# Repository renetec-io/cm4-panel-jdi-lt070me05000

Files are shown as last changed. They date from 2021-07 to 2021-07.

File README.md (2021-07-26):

Overview
======

This repository contains a PCB design and drivers for Raspberry Pi CM4 Сarrier with Hi-Res MIPI Display project.<br>
For details, see https://hackaday.io/project/176098-raspberry-pi-cm4-arrier-with-hi-res-mipi-display

The display used is JDI LT070ME05000 with Goodix touch input driver IC. The project also uses MCP23008 IO expander to save some GPIO pins.

Raspberry Pi only supports its official 7-inch MIPI DSI display with FKMS(Fake/Firmware KMS) out of the box. 
To make the display work, we need to use full KMS and Linux kernel driver for the panel.

The PCB design is contained in the KiCAD directory.

Setup
======

1. Install the latest Raspberry PI OS image, either on SD card (with CM4 Lite) or onto eMMC.
   With Lite version, you can use [SD card instruction](https://www.raspberrypi.org/documentation/installation/installing-images), 
   otherwise use [eMMC instruction](https://www.raspberrypi.org/documentation/hardware/computemodule/cm-emmc-flashing.md).   
   The jumper that enables boot from usb is located near the micro-USB connector on the PCB.
   
1. Mount `boot` partition onto your computer.

1. Enable and connect the serial console.
   1. Add `enable_uart=1` to the config.txt file on `boot` partition.   
   1. Use the serial interface to connect to Raspberry Pi: [elinux.org instruction](https://elinux.org/RPi_Serial_Connection).   
   
1. Enable USB port. <br>
   By default, to conserve power, USB is not enabled on CM4.<br>
   To enable, add `dtoverlay=dwc2,dr_mode=host` to config.txt.
   
1. Boot your Raspberry Pi and connect it to the internet. If you have a module without Wi-Fi, 
   you need a USB Wi-Fi or Ethernet adapter. 
   If Wi-Fi doesn't work, and you are receiving the message like "Could not communicate with wpa_supplicant" from raspi-config 
   when trying to set up wireless network, you may need to add the following
   ```
   allow-hotplug wlan0
   iface wlan0 inet manual
   wpa-conf /etc/wpa_supplicant/wpa_supplicant.conf
   ```
   to /etc/network/interfaces and then reboot.

1. On the Raspberry Pi, 
   1. Install git and dkms: 
   ```
   sudo apt-get update
   sudo apt-get install git dkms
   ```
   2. Clone the repository and install the drivers
   ```
   git clone https://github.com/renetec-io/cm4-panel-jdi-lt070me05000.git
   cd cm4-panel-jdi-lt070me05000
   ./setup.sh
   ```

1. Enable display driver.<br>
   Add the following in the end of /boot/config.txt:
   ```
   dtparam=i2c_vc=on   
   lcd_ignore=1   
   dtoverlay=vc4-kms-v3d-pi4,noaudio   
   dtoverlay=cm4-dsi-lt070me05000   
   ```
   
1. Enable sound.<br>
   Add the following to /boot/config.txt:
   ```
   # Sound configuration   
   dtparam=audio=on   
   dtoverlay=hifiberry-dac   
   dtoverlay=i2s-mmap   
   ```   

8. Reboot.

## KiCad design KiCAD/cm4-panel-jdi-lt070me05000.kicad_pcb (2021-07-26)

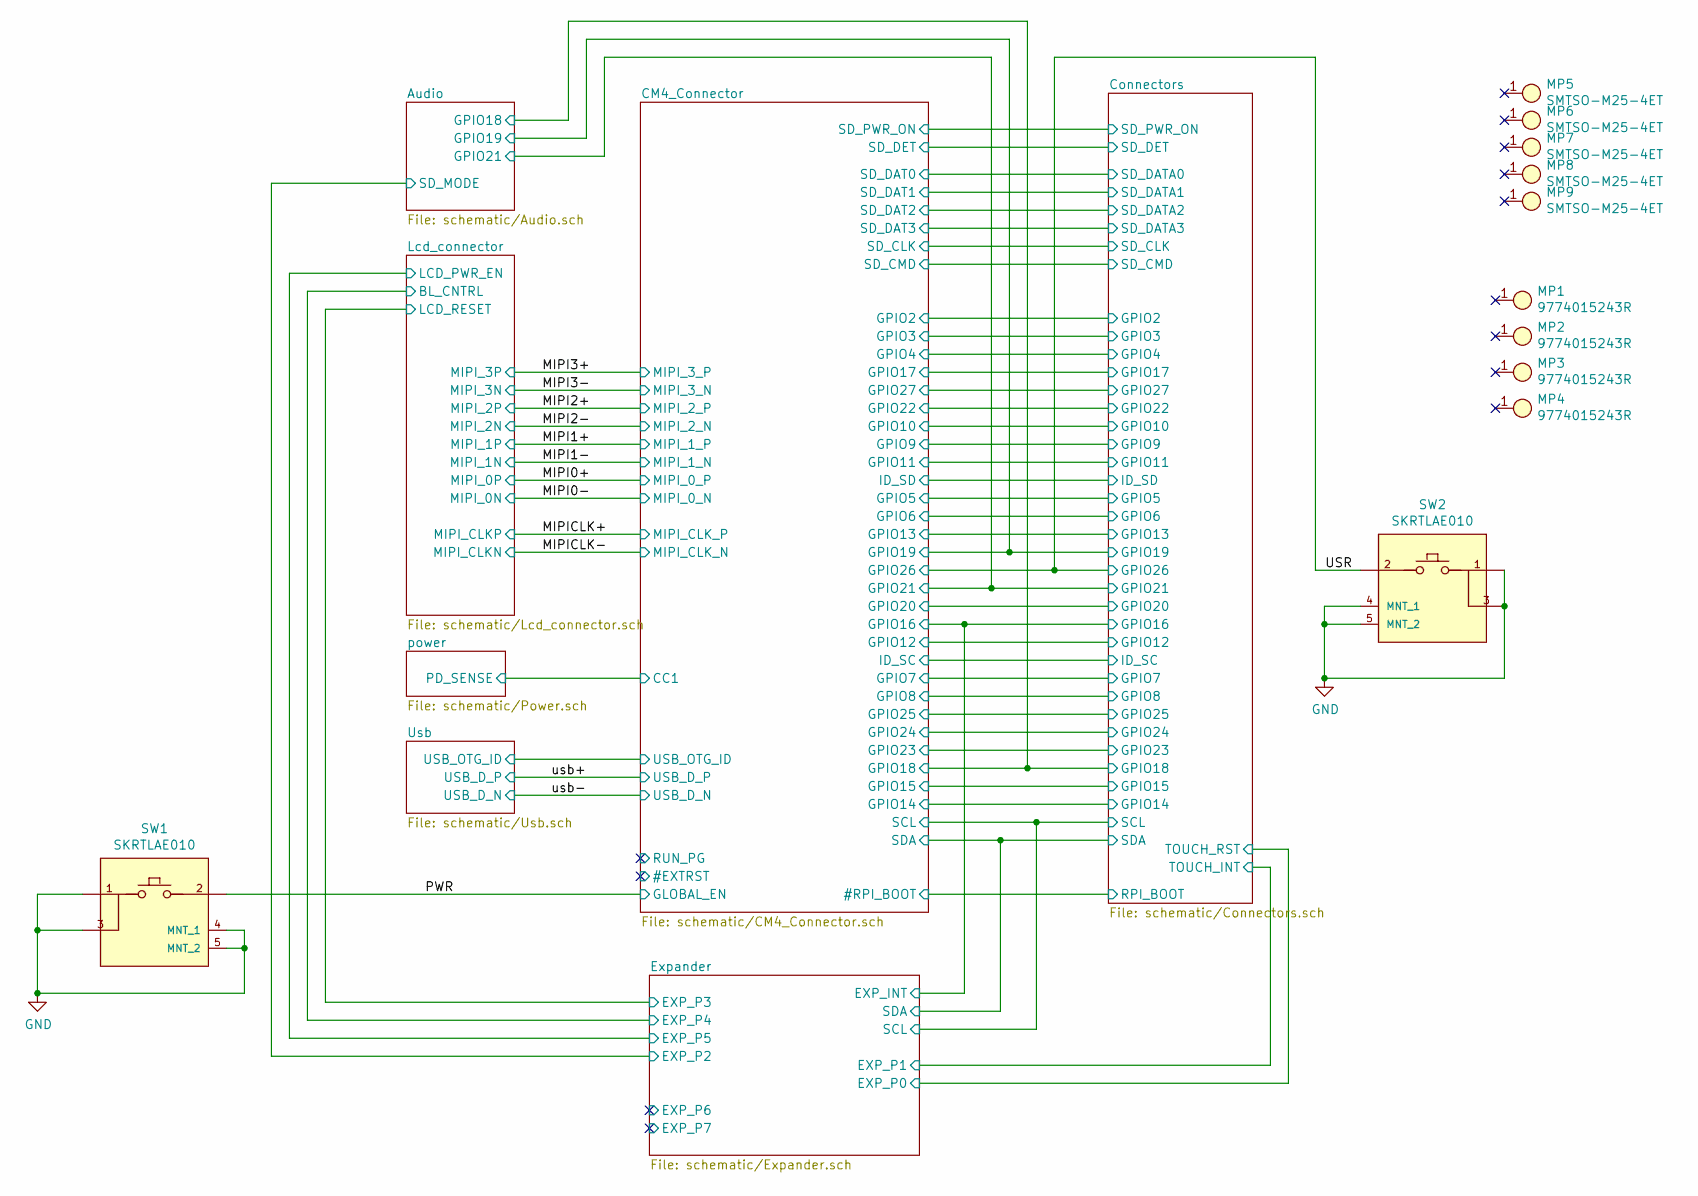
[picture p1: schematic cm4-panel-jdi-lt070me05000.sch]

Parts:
MP1, MP2, MP3, MP4: 9774015243R
MP5, MP6, MP7, MP8, MP9: SMTSO-M25-4ET
SW1, SW2: SKRTLAE010; ALPS-SKRTLAE010-0-0-0; voltage rating DC 12V; mouser part number 688-SKRTLA; mouser description Switch Tactile N.O. SPST Round Button J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

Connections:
/PWR: SW1.2; also elsewhere on the board
/USR: SW2.2; also elsewhere on the board
GND: SW1.1, SW1.3, SW1.4 (MNT_1), SW1.5 (MNT_2), SW2.1, SW2.3, SW2.4 (MNT_1), SW2.5 (MNT_2); also elsewhere on the board

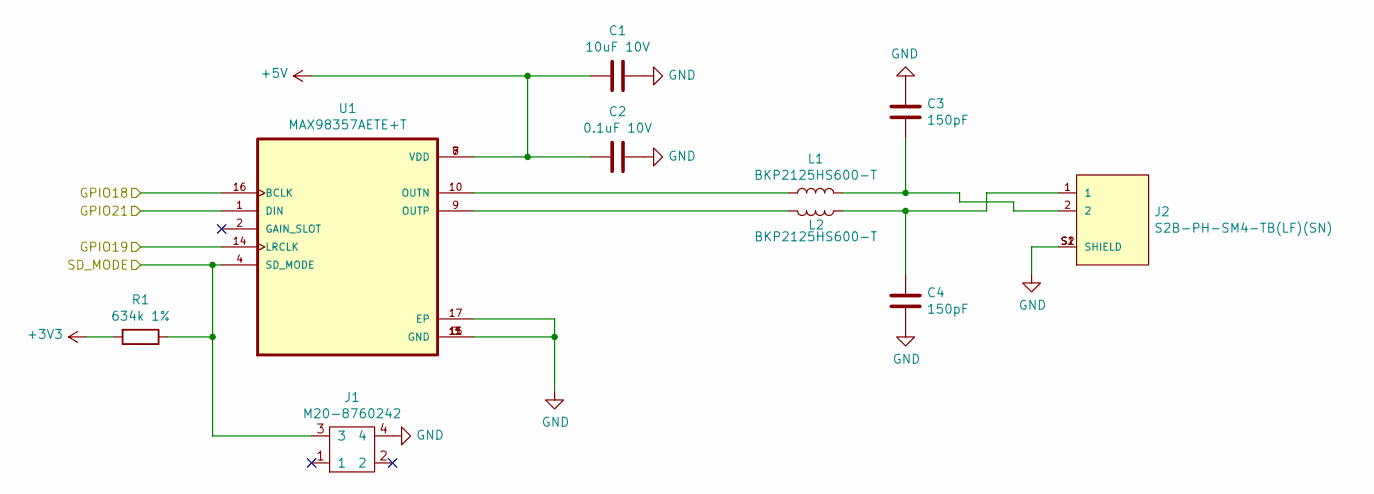
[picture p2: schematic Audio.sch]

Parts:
C1: 10uF 10V; C_0603_1608Metric
C2: 0.1uF 10V; C_0603_1608Metric
C3, C4: 150pF; C_0603_1608Metric
J1: M20-8760242
J2: S2B-PH-SM4-TB(LF)(SN); JST_S2B-PH-SM4-TB(LF)(SN)
L1, L2: BKP2125HS600-T; L_0805_2012Metric
R1: 634k 1%; R_0603_1608Metric
U1: MAX98357AETE+T; QFN50P300X300X80-17N

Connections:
+3V3: R1.2; also elsewhere on the board
+5V: C1.2, C2.2, U1.7 (VDD), U1.8 (VDD); also elsewhere on the board
/Audio/GPIO18: U1.16 (BCLK); also elsewhere on the board
/Audio/GPIO19: U1.14 (LRCLK); also elsewhere on the board
/Audio/GPIO21: U1.1 (DIN); also elsewhere on the board
/Expander/EXP_P2: J1.3, R1.1, U1.4 (SD_MODE); also elsewhere on the board
GND: C1.1, C2.1, C3.2, C4.1, J1.4, J2.S1 (SHIELD), J2.S2 (SHIELD), U1.3 (GND), U1.11 (GND), U1.15 (GND), U1.17 (EP); also elsewhere on the board
unnamed: C3.1, J2.2, L1.2
unnamed: C4.2, J2.1, L2.2
unnamed: L1.1, U1.10 (OUTN)
unnamed: L2.1, U1.9 (OUTP)

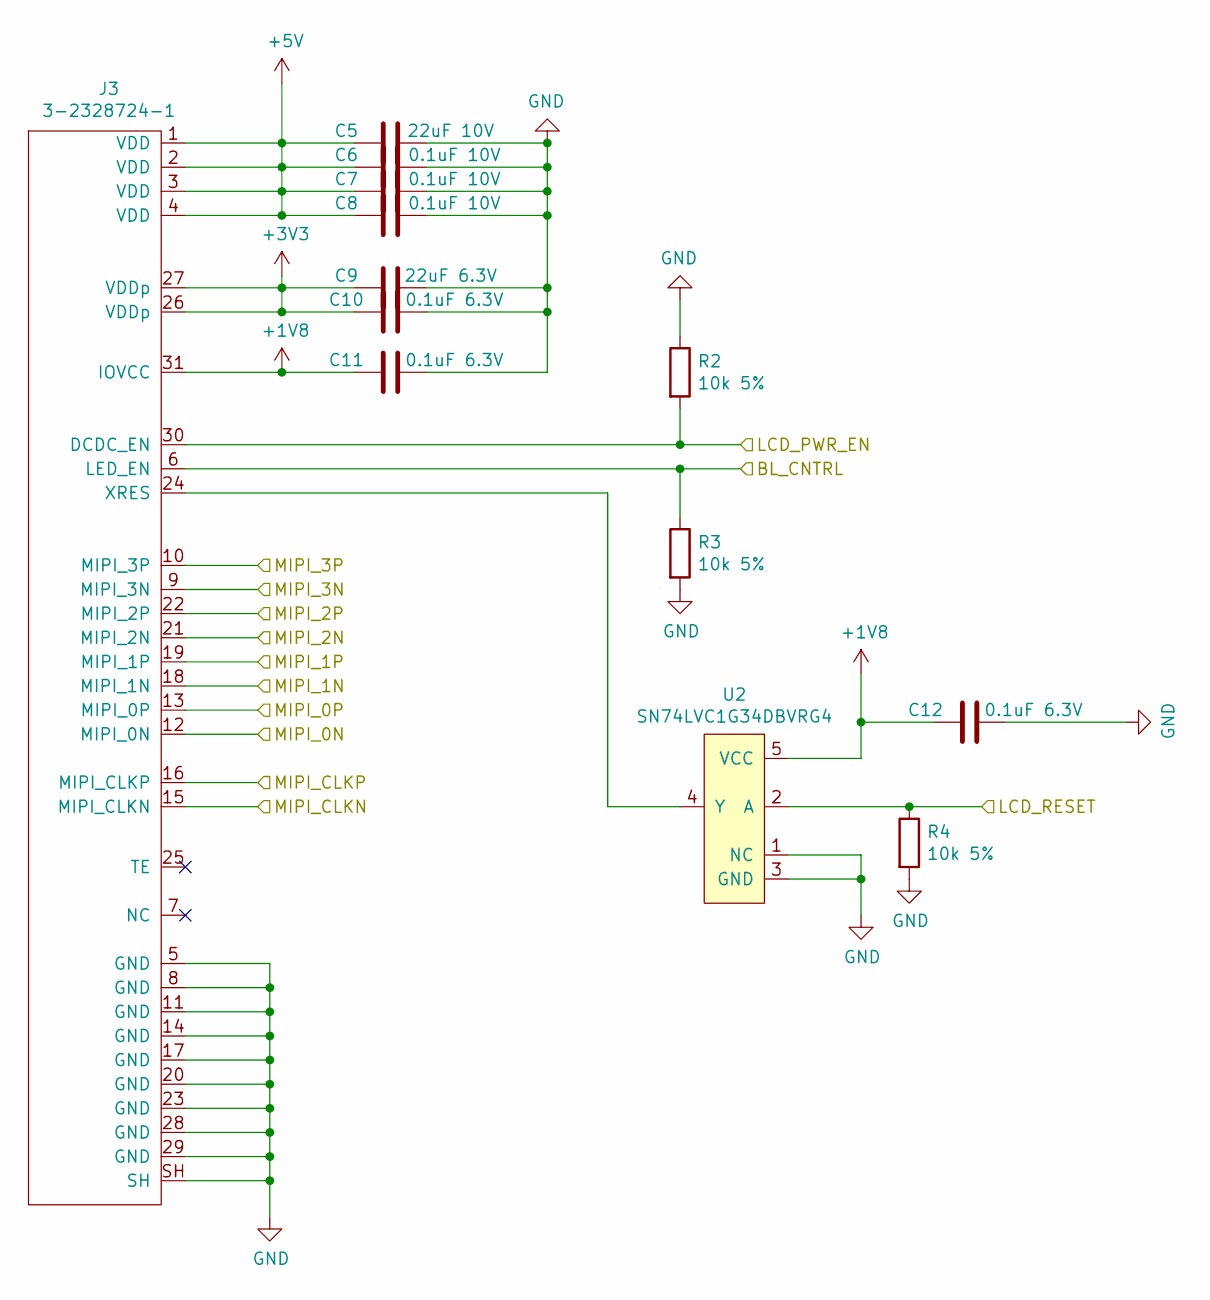
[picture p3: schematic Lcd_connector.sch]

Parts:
C5: 22uF 10V; C_0805_2012Metric
C6, C7, C8: 0.1uF 10V; C_0603_1608Metric
C9: 22uF 6.3V; C_0805_2012Metric
C10, C11, C12: 0.1uF 6.3V; C_0603_1608Metric
J3: 3-2328724-1
R2, R3, R4: 10k 5%; R_0603_1608Metric
U2: SN74LVC1G34DBVRG4; SOT95P280X145-5N

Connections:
+1V8: C11.2, C12.2, J3.31 (IOVCC), U2.5 (VCC); also elsewhere on the board
+3V3: C9.2, C10.2, J3.26 (VDDp), J3.27 (VDDp); also elsewhere on the board
+5V: C5.2, C6.2, C7.2, C8.2, J3.1 (VDD), J3.2 (VDD), J3.3 (VDD), J3.4 (VDD); also elsewhere on the board
/Expander/EXP_P3: R4.1, U2.2 (A); also elsewhere on the board
/Expander/EXP_P5: J3.30 (DCDC_EN), R2.2; also elsewhere on the board
/Lcd_connector/BL_CNTRL: J3.6 (LED_EN), R3.1; also elsewhere on the board
/MIPI0+: J3.13 (MIPI_0P); also elsewhere on the board
/MIPI0-: J3.12 (MIPI_0N); also elsewhere on the board
/MIPI1+: J3.19 (MIPI_1P); also elsewhere on the board
/MIPI1-: J3.18 (MIPI_1N); also elsewhere on the board
/MIPI2+: J3.22 (MIPI_2P); also elsewhere on the board
/MIPI2-: J3.21 (MIPI_2N); also elsewhere on the board
/MIPI3+: J3.10 (MIPI_3P); also elsewhere on the board
/MIPI3-: J3.9 (MIPI_3N); also elsewhere on the board
/MIPICLK+: J3.16 (MIPI_CLKP); also elsewhere on the board
/MIPICLK-: J3.15 (MIPI_CLKN); also elsewhere on the board
GND: C5.1, C6.1, C7.1, C8.1, C9.1, C10.1, C11.1, C12.1, J3.5 (GND), J3.8 (GND), J3.11 (GND), J3.14 (GND), J3.17 (GND), J3.20 (GND), J3.23 (GND), J3.28 (GND), J3.29 (GND), J3.SH, R2.1, R3.2, R4.2, U2.1 (NC), U2.3 (GND); also elsewhere on the board
unnamed: J3.24 (XRES), U2.4 (Y)

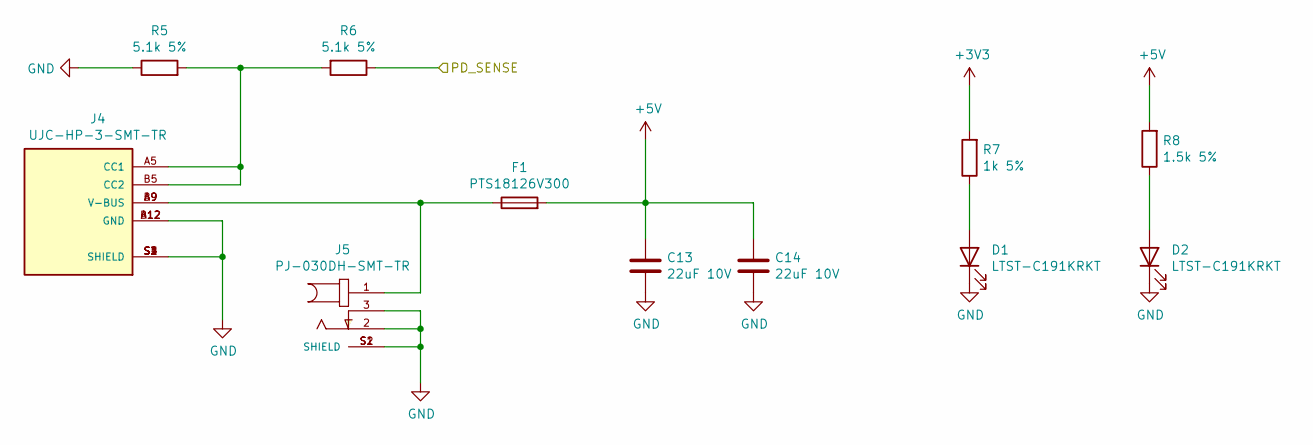
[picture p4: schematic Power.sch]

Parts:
C13, C14: 22uF 10V; C_0805_2012Metric
D1, D2: LTST-C191KRKT; LED_0603_1608Metric
F1: PTS18126V300; Fuse_1812_4532Metric
J4: UJC-HP-3-SMT-TR; CUI_UJC-HP-3-SMT-TR; PARTREV 1.0
J5: PJ-030DH-SMT-TR; CUI_PJ-030DH-SMT-TR; PARTREV 1.03
R5, R6: 5.1k 5%; R_0603_1608Metric
R7: 1k 5%; R_0603_1608Metric
R8: 1.5k 5%; R_0603_1608Metric

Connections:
+3V3: R7.2; also elsewhere on the board
+5V: C13.1, C14.1, F1.2, R8.2; also elsewhere on the board
/CM4_Connector/CC1: R6.1; also elsewhere on the board
GND: C13.2, C14.2, D1.1 (K), D2.1 (K), J4.A12 (GND), J4.B12 (GND), J4.S1 (SHIELD), J4.S2 (SHIELD), J4.S3 (SHIELD), J4.S4 (SHIELD), J5.2, J5.3, J5.S1 (SHIELD), J5.S2 (SHIELD), R5.1; also elsewhere on the board
unnamed: D1.2 (A), R7.1
unnamed: D2.2 (A), R8.1
unnamed: F1.1, J4.A9 (V-BUS), J4.B9 (V-BUS), J5.1
unnamed: J4.A5 (CC1), J4.B5 (CC2), R5.2, R6.2

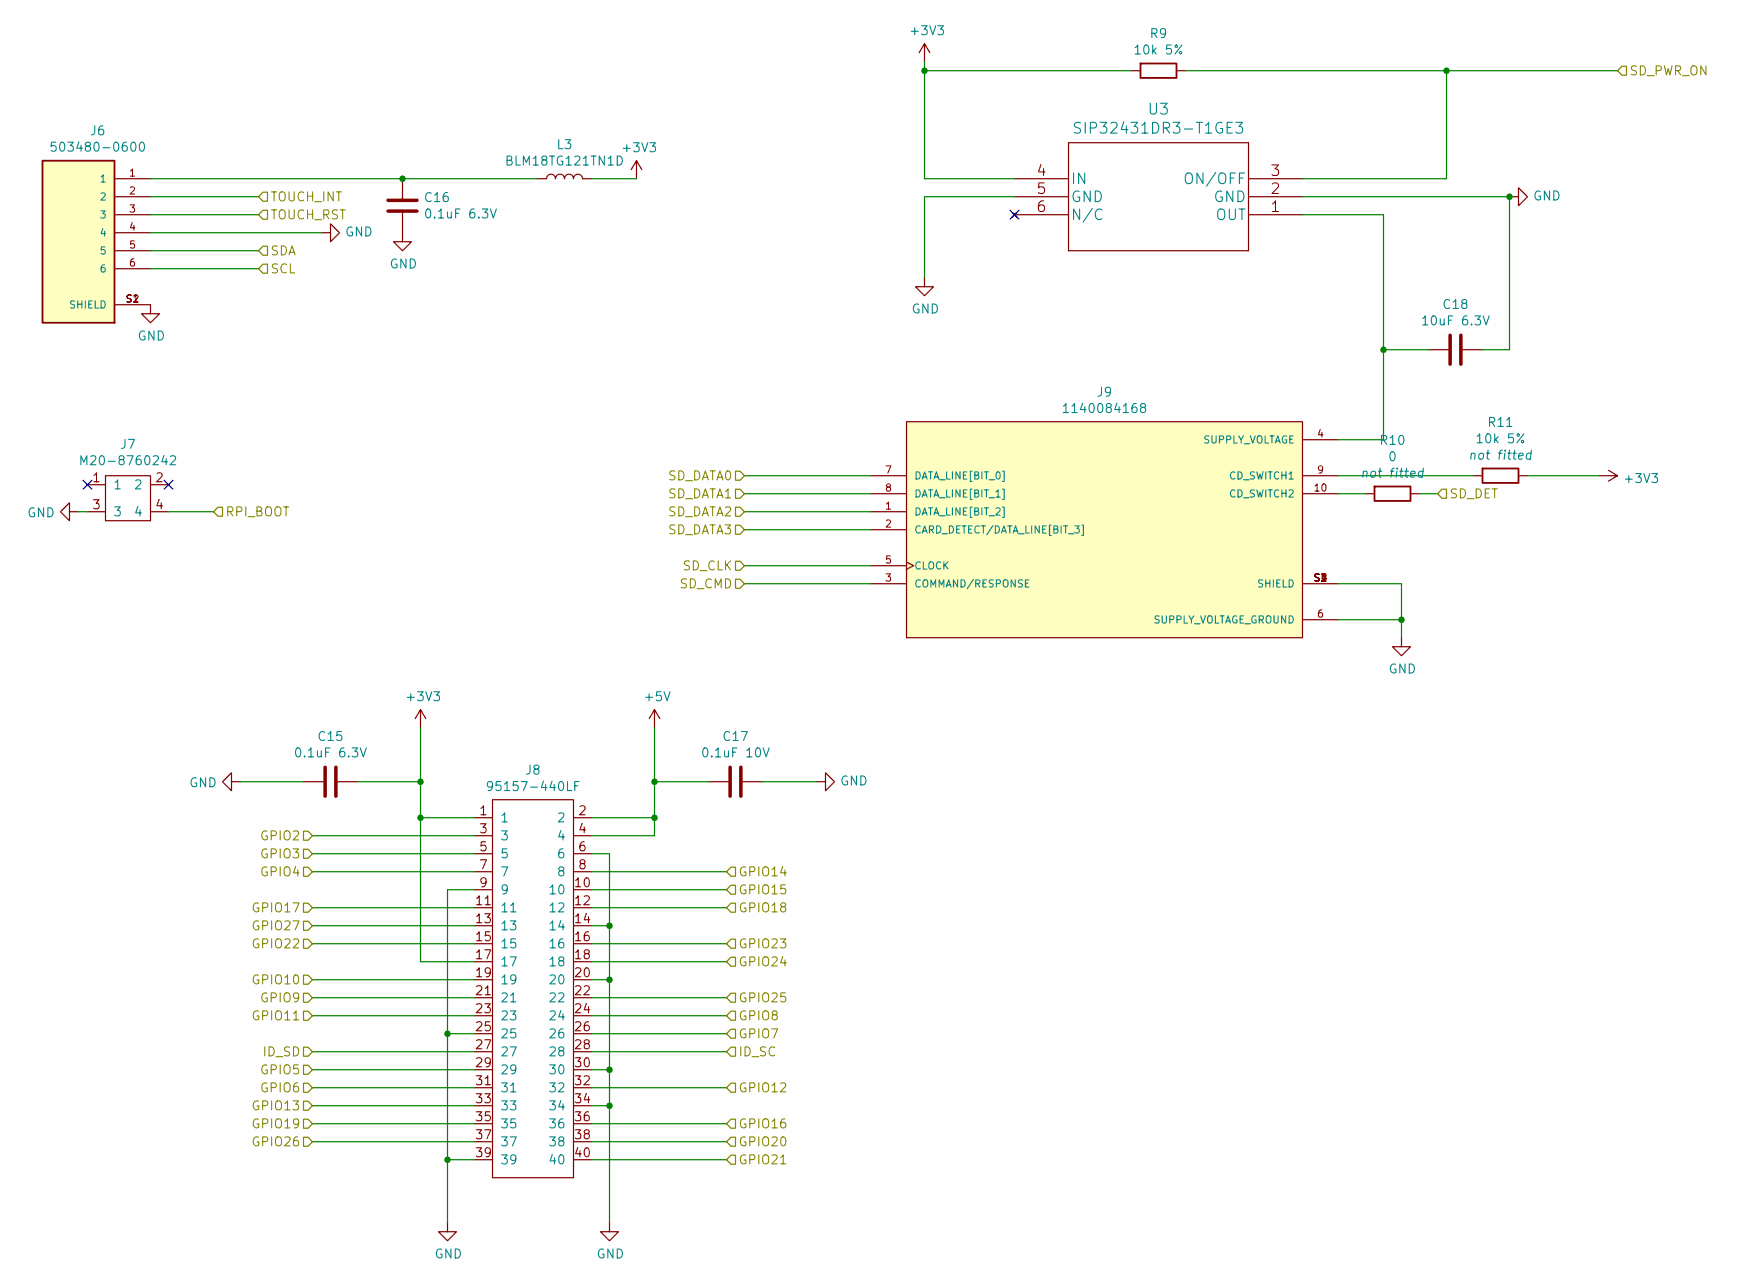
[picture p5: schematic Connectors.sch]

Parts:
C15, C16: 0.1uF 6.3V; C_0603_1608Metric
C17: 0.1uF 10V; C_0603_1608Metric
C18: 10uF 6.3V; C_0603_1608Metric
J6: 503480-0600; MOLEX_503480-0600; PARTREV H
J7: M20-8760242
J8: 95157-440LF
J9: 1140084168; AMPHENOL_1140084168; PARTREV A
L3: BLM18TG121TN1D; L_0603_1608Metric
R9, R11: 10k 5%; R_0603_1608Metric
R10: 0; R_0603_1608Metric
U3: SIP32431DR3-T1GE3

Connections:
+3V3: C15.1, J8.1, J8.17, L3.2, R9.2, R11.1, U3.4 (IN); also elsewhere on the board
+5V: C17.2, J8.2, J8.4; also elsewhere on the board
/Audio/GPIO18: J8.12; also elsewhere on the board
/Audio/GPIO19: J8.35; also elsewhere on the board
/Audio/GPIO21: J8.40; also elsewhere on the board
/CM4_Connector/#RPI_BOOT: J7.4; also elsewhere on the board
/CM4_Connector/GPIO2: J8.3; also elsewhere on the board
/CM4_Connector/GPIO3: J8.5; also elsewhere on the board
/CM4_Connector/GPIO4: J8.7; also elsewhere on the board
/CM4_Connector/GPIO5: J8.29; also elsewhere on the board
/CM4_Connector/GPIO6: J8.31; also elsewhere on the board
/CM4_Connector/GPIO7: J8.26; also elsewhere on the board
/CM4_Connector/GPIO8: J8.24; also elsewhere on the board
/CM4_Connector/GPIO9: J8.21; also elsewhere on the board
/CM4_Connector/GPIO10: J8.19; also elsewhere on the board
/CM4_Connector/GPIO11: J8.23; also elsewhere on the board
/CM4_Connector/GPIO12: J8.32; also elsewhere on the board
/CM4_Connector/GPIO13: J8.33; also elsewhere on the board
/CM4_Connector/GPIO14: J8.8; also elsewhere on the board
/CM4_Connector/GPIO15: J8.10; also elsewhere on the board
/CM4_Connector/GPIO17: J8.11; also elsewhere on the board
/CM4_Connector/GPIO20: J8.38; also elsewhere on the board
/CM4_Connector/GPIO22: J8.15; also elsewhere on the board
/CM4_Connector/GPIO23: J8.16; also elsewhere on the board
/CM4_Connector/GPIO24: J8.18; also elsewhere on the board
/CM4_Connector/GPIO25: J8.22; also elsewhere on the board
/CM4_Connector/GPIO27: J8.13; also elsewhere on the board
/CM4_Connector/ID_SC: J8.28; also elsewhere on the board
/CM4_Connector/ID_SD: J8.27; also elsewhere on the board
/CM4_Connector/SCL: J6.6; also elsewhere on the board
/CM4_Connector/SDA: J6.5; also elsewhere on the board
/CM4_Connector/SD_CLK: J9.5 (CLOCK); also elsewhere on the board
/CM4_Connector/SD_CMD: J9.3 (COMMAND/RESPONSE); also elsewhere on the board
/CM4_Connector/SD_DAT0: J9.7 (DATA_LINE[BIT_0]); also elsewhere on the board
/CM4_Connector/SD_DAT1: J9.8 (DATA_LINE[BIT_1]); also elsewhere on the board
/CM4_Connector/SD_DAT2: J9.1 (DATA_LINE[BIT_2]); also elsewhere on the board
/CM4_Connector/SD_DAT3: J9.2 (CARD_DETECT/DATA_LINE[BIT_3]); also elsewhere on the board
/CM4_Connector/SD_DET: R10.1; also elsewhere on the board
/CM4_Connector/SD_PWR_ON: R9.1, U3.3 (ON/OFF); also elsewhere on the board
/Expander/EXP_INT: J8.36; also elsewhere on the board
/Expander/EXP_P0: J6.3; also elsewhere on the board
/Expander/EXP_P1: J6.2; also elsewhere on the board
/USR: J8.37; also elsewhere on the board
GND: C15.2, C16.1, C17.1, C18.1, J6.4, J6.S1 (SHIELD), J6.S2 (SHIELD), J7.3, J8.6, J8.9, J8.14, J8.20, J8.25, J8.30, J8.34, J8.39, J9.6 (SUPPLY_VOLTAGE_GROUND), J9.S1 (SHIELD), J9.S2 (SHIELD), J9.S3 (SHIELD), J9.S4 (SHIELD), U3.2 (GND), U3.5 (GND); also elsewhere on the board
unnamed: C16.2, J6.1, L3.1
unnamed: C18.2, J9.4 (SUPPLY_VOLTAGE), U3.1 (OUT)
unnamed: J9.9 (CD_SWITCH1), R11.2
unnamed: J9.10 (CD_SWITCH2), R10.2

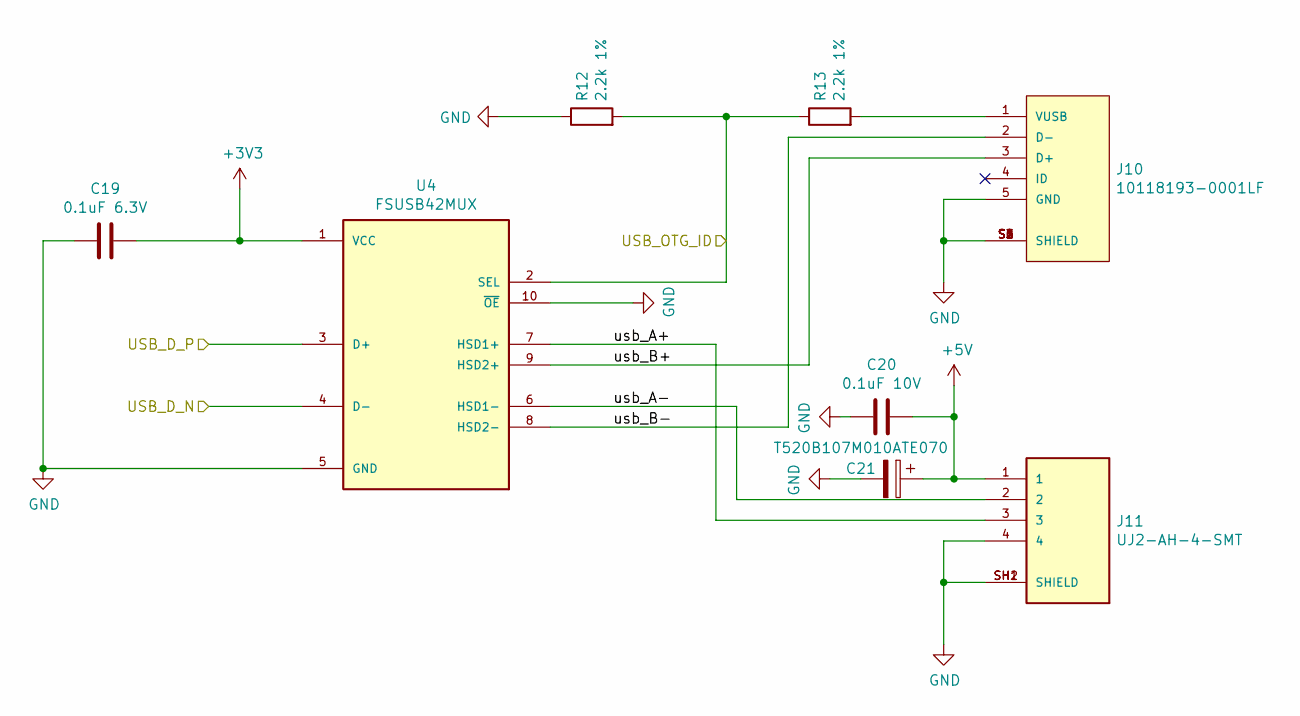
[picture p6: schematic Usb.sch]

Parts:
C19: 0.1uF 6.3V; C_0603_1608Metric
C20: 0.1uF 10V; C_0603_1608Metric
C21: T520B107M010ATE070; T520B227M006ATE045
J10: 10118193-0001LF; FCI_10118193-0001LF
J11: UJ2-AH-4-SMT; CUI_UJ2-AH-4-SMT; PART_REV 1.01
R12, R13: 2.2k 1%; R_0603_1608Metric
U4: FSUSB42MUX; SOP50P490X110-10N; PARTREV 1.25

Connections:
+3V3: C19.1, U4.1 (VCC); also elsewhere on the board
+5V: C20.1, C21.1, J11.1; also elsewhere on the board
/CM4_Connector/USB_OTG_ID: R12.2, R13.1, U4.2 (SEL); also elsewhere on the board
/Usb/usb_A+: J11.3, U4.7 (HSD1+)
/Usb/usb_A-: J11.2, U4.6 (HSD1-)
/Usb/usb_B+: J10.3 (D+), U4.9 (HSD2+)
/Usb/usb_B-: J10.2 (D-), U4.8 (HSD2-)
/usb+: U4.3 (D+); also elsewhere on the board
/usb-: U4.4 (D-); also elsewhere on the board
GND: C19.2, C20.2, C21.2, J10.5 (GND), J10.S1 (SHIELD), J10.S2 (SHIELD), J10.S3 (SHIELD), J10.S4 (SHIELD), J10.S5 (SHIELD), J10.S6 (SHIELD), J11.4, J11.SH1 (SHIELD), J11.SH2 (SHIELD), R12.1, U4.5 (GND), U4.10 (~OE); also elsewhere on the board
unnamed: J10.1 (VUSB), R13.2

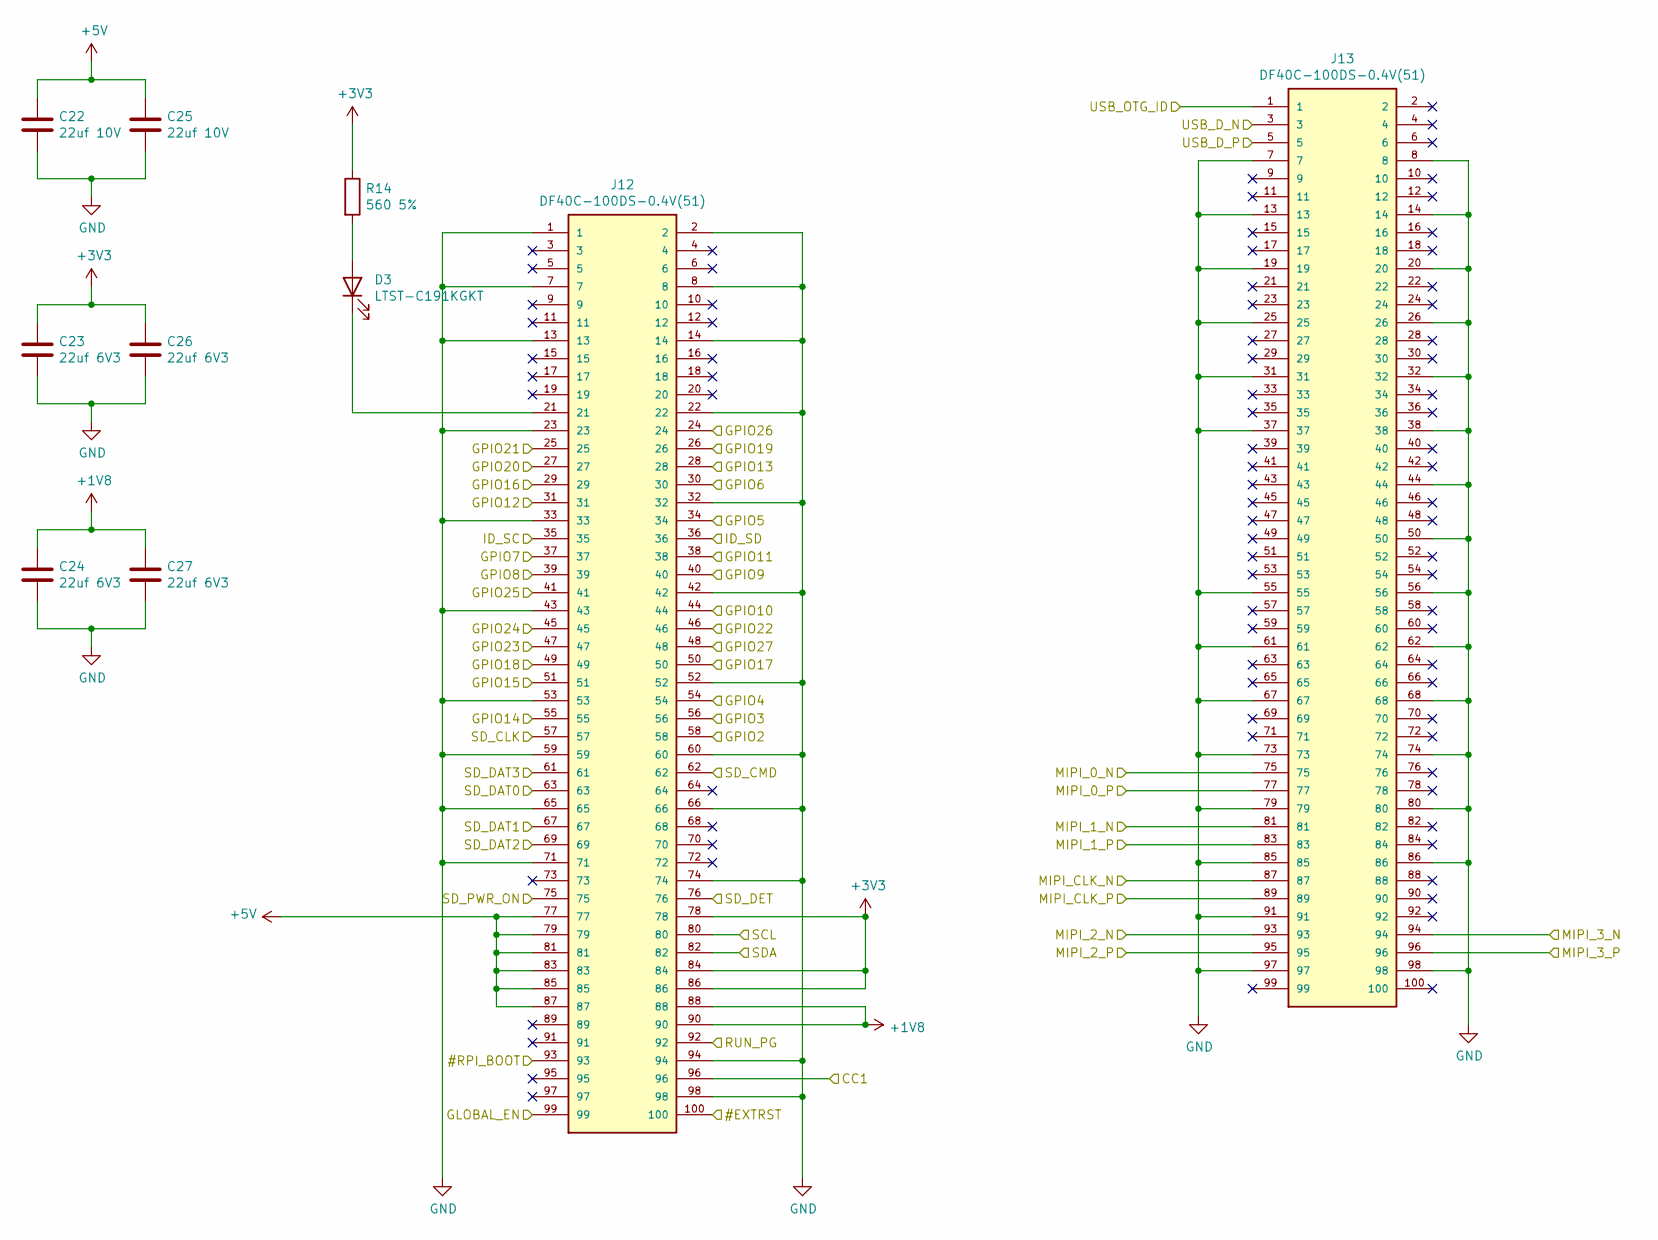
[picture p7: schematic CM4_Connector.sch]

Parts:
C22, C25: 22uf 10V; C_0805_2012Metric
C23, C24, C26, C27: 22uf 6V3; C_0805_2012Metric
D3: LTST-C191KGKT; LED_0603_1608Metric
J12, J13: DF40C-100DS-0.4V(51); HRS_DF40C-100DS-0.4V(51)
R14: 560 5%; R_0603_1608Metric

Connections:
+1V8: C24.1, C27.1, J12.88, J12.90; also elsewhere on the board
+3V3: C23.1, C26.1, J12.78, J12.84, J12.86, R14.1; also elsewhere on the board
+5V: C22.1, C25.1, J12.77, J12.79, J12.81, J12.83, J12.85, J12.87; also elsewhere on the board
/Audio/GPIO18: J12.49; also elsewhere on the board
/Audio/GPIO19: J12.26; also elsewhere on the board
/Audio/GPIO21: J12.25; also elsewhere on the board
/CM4_Connector/#EXTRST: J12.100
/CM4_Connector/#RPI_BOOT: J12.93; also elsewhere on the board
/CM4_Connector/CC1: J12.96; also elsewhere on the board
/CM4_Connector/GPIO2: J12.58; also elsewhere on the board
/CM4_Connector/GPIO3: J12.56; also elsewhere on the board
/CM4_Connector/GPIO4: J12.54; also elsewhere on the board
/CM4_Connector/GPIO5: J12.34; also elsewhere on the board
/CM4_Connector/GPIO6: J12.30; also elsewhere on the board
/CM4_Connector/GPIO7: J12.37; also elsewhere on the board
/CM4_Connector/GPIO8: J12.39; also elsewhere on the board
/CM4_Connector/GPIO9: J12.40; also elsewhere on the board
/CM4_Connector/GPIO10: J12.44; also elsewhere on the board
/CM4_Connector/GPIO11: J12.38; also elsewhere on the board
/CM4_Connector/GPIO12: J12.31; also elsewhere on the board
/CM4_Connector/GPIO13: J12.28; also elsewhere on the board
/CM4_Connector/GPIO14: J12.55; also elsewhere on the board
/CM4_Connector/GPIO15: J12.51; also elsewhere on the board
/CM4_Connector/GPIO17: J12.50; also elsewhere on the board
/CM4_Connector/GPIO20: J12.27; also elsewhere on the board
/CM4_Connector/GPIO22: J12.46; also elsewhere on the board
/CM4_Connector/GPIO23: J12.47; also elsewhere on the board
/CM4_Connector/GPIO24: J12.45; also elsewhere on the board
/CM4_Connector/GPIO25: J12.41; also elsewhere on the board
/CM4_Connector/GPIO27: J12.48; also elsewhere on the board
/CM4_Connector/ID_SC: J12.35; also elsewhere on the board
/CM4_Connector/ID_SD: J12.36; also elsewhere on the board
/CM4_Connector/RUN_PG: J12.92
/CM4_Connector/SCL: J12.80; also elsewhere on the board
/CM4_Connector/SDA: J12.82; also elsewhere on the board
/CM4_Connector/SD_CLK: J12.57; also elsewhere on the board
/CM4_Connector/SD_CMD: J12.62; also elsewhere on the board
/CM4_Connector/SD_DAT0: J12.63; also elsewhere on the board
/CM4_Connector/SD_DAT1: J12.67; also elsewhere on the board
/CM4_Connector/SD_DAT2: J12.69; also elsewhere on the board
/CM4_Connector/SD_DAT3: J12.61; also elsewhere on the board
/CM4_Connector/SD_DET: J12.76; also elsewhere on the board
/CM4_Connector/SD_PWR_ON: J12.75; also elsewhere on the board
/CM4_Connector/USB_OTG_ID: J13.1; also elsewhere on the board
/Expander/EXP_INT: J12.29; also elsewhere on the board
/MIPI0+: J13.77; also elsewhere on the board
/MIPI0-: J13.75; also elsewhere on the board
/MIPI1+: J13.83; also elsewhere on the board
/MIPI1-: J13.81; also elsewhere on the board
/MIPI2+: J13.95; also elsewhere on the board
/MIPI2-: J13.93; also elsewhere on the board
/MIPI3+: J13.96; also elsewhere on the board
/MIPI3-: J13.94; also elsewhere on the board
/MIPICLK+: J13.89; also elsewhere on the board
/MIPICLK-: J13.87; also elsewhere on the board
/PWR: J12.99; also elsewhere on the board
/USR: J12.24; also elsewhere on the board
/usb+: J13.5; also elsewhere on the board
/usb-: J13.3; also elsewhere on the board
GND: C22.2, C23.2, C24.2, C25.2, C26.2, C27.2, J12.1, J12.2, J12.7, J12.8, J12.13, J12.14, J12.22, J12.23, J12.32, J12.33, J12.42, J12.43, J12.52, J12.53, J12.59, J12.60, J12.65, J12.66, J12.71, J12.74, J12.94, J12.98, J13.7, J13.8, J13.13, J13.14, J13.19, J13.20, J13.25, J13.26, J13.31, J13.32, J13.37, J13.38, J13.44, J13.50, J13.55, J13.56, J13.61, J13.62, J13.67, J13.68, J13.73, J13.74, J13.79, J13.80, J13.85, J13.86, J13.91, J13.97, J13.98; also elsewhere on the board
unnamed: D3.1 (K), J12.21
unnamed: D3.2 (A), R14.2

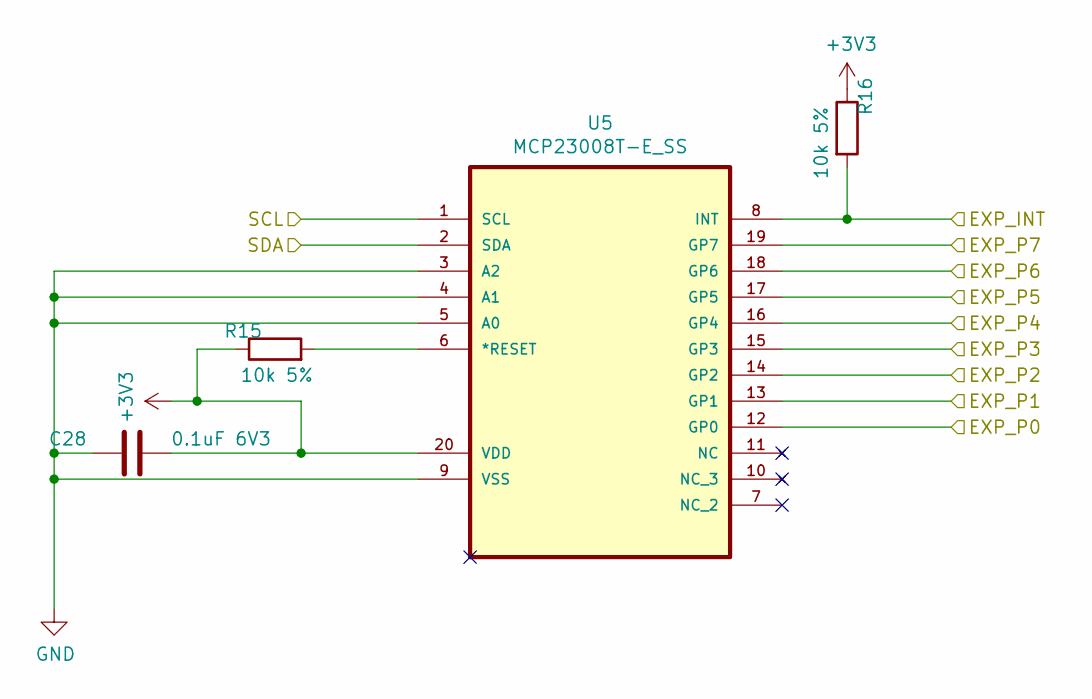
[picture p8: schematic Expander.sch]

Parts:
C28: 0.1uF 6V3; C_0603_1608Metric
R15, R16: 10k 5%; R_0603_1608Metric
U5: MCP23008T-E_SS; SOP65P780X200-20N; MPN MCP23008T-E/SS

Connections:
+3V3: C28.2, R15.1, R16.1, U5.20 (VDD); also elsewhere on the board
/CM4_Connector/SCL: U5.1 (SCL); also elsewhere on the board
/CM4_Connector/SDA: U5.2 (SDA); also elsewhere on the board
/Expander/EXP_INT: R16.2, U5.8 (INT); also elsewhere on the board
/Expander/EXP_P0: U5.12 (GP0); also elsewhere on the board
/Expander/EXP_P1: U5.13 (GP1); also elsewhere on the board
/Expander/EXP_P2: U5.14 (GP2); also elsewhere on the board
/Expander/EXP_P3: U5.15 (GP3); also elsewhere on the board
/Expander/EXP_P5: U5.17 (GP5); also elsewhere on the board
/Expander/EXP_P6: U5.18 (GP6)
/Expander/EXP_P7: U5.19 (GP7)
/Lcd_connector/BL_CNTRL: U5.16 (GP4); also elsewhere on the board
GND: C28.1, U5.3 (A2), U5.4 (A1), U5.5 (A0), U5.9 (VSS); also elsewhere on the board
unnamed: R15.2, U5.6 (*RESET)

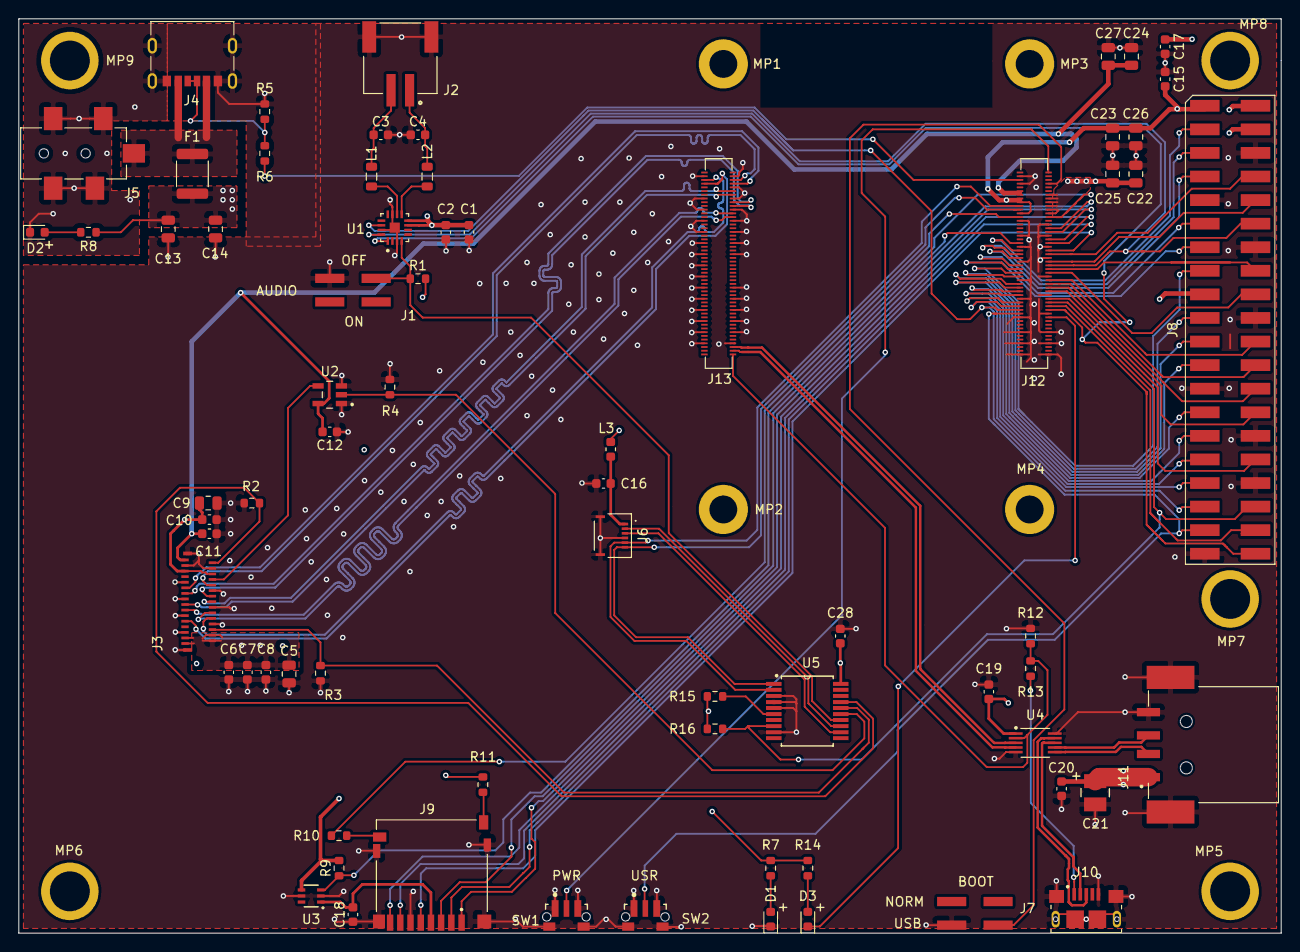
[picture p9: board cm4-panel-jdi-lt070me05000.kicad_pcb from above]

Board: 4 copper layers, 136.0 x 98.5 mm, 80 parts (0 on the bottom side), 85 nets.

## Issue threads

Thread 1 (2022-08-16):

Problem with pcb library

Kuzma30, 2022-08-16:
Hello. I want create custom project based on your work.
I create schematic without problem (copy-paste method) add new features. Now when I start PCB work I get many errors like this
Error: Cannot add J6 (footprint 'footprintlib:HRS_DF40C-100DS-0.4V(51)' not found).
Error: Cannot add J5 (footprint 'footprintlib:HRS_DF40C-100DS-0.4V(51)' not found).

As I understand must be a footprintlib file (I am newbie in Kicad). Where I can get it?

Closed 2022-12-27.

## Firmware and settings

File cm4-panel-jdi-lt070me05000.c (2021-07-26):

// SPDX-License-Identifier: GPL-2.0-only
/*
 * Copyright (C) 2016 InforceComputing
 * Author: Vinay Simha BN <simhavcs@gmail.com>
 *
 * Copyright (C) 2016 Linaro Ltd
 * Author: Sumit Semwal <sumit.semwal@linaro.org>
 *
 * From internet archives, the panel for Nexus 7 2nd Gen, 2013 model is a
 * JDI model LT070ME05000, and its data sheet is at:
 * http://panelone.net/en/7-0-inch/JDI_LT070ME05000_7.0_inch-datasheet
 */

#include <linux/backlight.h>
#include <linux/delay.h>
#include <linux/gpio/consumer.h>
#include <linux/module.h>
#include <linux/of.h>
#include <linux/regulator/consumer.h>

#include <video/mipi_display.h>

#include <drm/drm_crtc.h>
#include <drm/drm_mipi_dsi.h>
#include <drm/drm_modes.h>
#include <drm/drm_panel.h>

static const char * const regulator_names[] = {
	"vddp",
	"iovcc"
};

struct jdi_panel {
	struct drm_panel base;
	struct mipi_dsi_device *dsi;

	struct regulator_bulk_data supplies[ARRAY_SIZE(regulator_names)];

	struct gpio_desc *enable_gpio;
	struct gpio_desc *reset_gpio;
	struct gpio_desc *dcdc_en_gpio;
	struct backlight_device *backlight;

	bool prepared;
	bool enabled;

	const struct drm_display_mode *mode;
};

static inline struct jdi_panel *to_jdi_panel(struct drm_panel *panel)
{
	return container_of(panel, struct jdi_panel, base);
}

static int jdi_panel_init(struct jdi_panel *jdi)
{
	struct mipi_dsi_device *dsi = jdi->dsi;
	struct device *dev = &jdi->dsi->dev;
	int ret;

	dsi->mode_flags |= MIPI_DSI_MODE_LPM;

	ret = mipi_dsi_dcs_soft_reset(dsi);
	if (ret < 0)
		return ret;

	usleep_range(10000, 20000);

	ret = mipi_dsi_dcs_set_pixel_format(dsi, MIPI_DCS_PIXEL_FMT_24BIT << 4);
	if (ret < 0) {
		dev_err(dev, "failed to set pixel format: %d\n", ret);
		return ret;
	}

	ret = mipi_dsi_dcs_set_column_address(dsi, 0, jdi->mode->hdisplay - 1);
	if (ret < 0) {
		dev_err(dev, "failed to set column address: %d\n", ret);
		return ret;
	}

	ret = mipi_dsi_dcs_set_page_address(dsi, 0, jdi->mode->vdisplay - 1);
	if (ret < 0) {
		dev_err(dev, "failed to set page address: %d\n", ret);
		return ret;
	}

	/*
	 * BIT(5) BCTRL = 1 Backlight Control Block On, Brightness registers
	 *                  are active
	 * BIT(3) BL = 1    Backlight Control On
	 * BIT(2) DD = 0    Display Dimming is Off
	 */
	ret = mipi_dsi_dcs_write(dsi, MIPI_DCS_WRITE_CONTROL_DISPLAY,
				 (u8[]){ 0x24 }, 1);
	if (ret < 0) {
		dev_err(dev, "failed to write control display: %d\n", ret);
		return ret;
	}

	/* CABC off */
	ret = mipi_dsi_dcs_write(dsi, MIPI_DCS_WRITE_POWER_SAVE,
				 (u8[]){ 0x00 }, 1);
	if (ret < 0) {
		dev_err(dev, "failed to set cabc off: %d\n", ret);
		return ret;
	}

	ret = mipi_dsi_dcs_exit_sleep_mode(dsi);
	if (ret < 0) {
		dev_err(dev, "failed to set exit sleep mode: %d\n", ret);
		return ret;
	}

	msleep(120);

	ret = mipi_dsi_generic_write(dsi, (u8[]){0xB0, 0x00}, 2);
	if (ret < 0) {
		dev_err(dev, "failed to set mcap: %d\n", ret);
		return ret;
	}

	mdelay(10);

	/* Interface setting, video mode */
	ret = mipi_dsi_generic_write(dsi, (u8[])
				     {0xB3, 0x26, 0x08, 0x00, 0x20, 0x00}, 6);
	if (ret < 0) {
		dev_err(dev, "failed to set display interface setting: %d\n"
			, ret);
		return ret;
	}

	mdelay(20);

	return 0;
}

static int jdi_panel_on(struct jdi_panel *jdi)
{
	struct mipi_dsi_device *dsi = jdi->dsi;
	struct device *dev = &jdi->dsi->dev;
	int ret;

	dsi->mode_flags |= MIPI_DSI_MODE_LPM;

	gpiod_set_value_cansleep(jdi->dcdc_en_gpio, 1);
	msleep(20);

	do {
		ret = mipi_dsi_dcs_exit_sleep_mode(dsi);
		if (ret < 0) {
			dev_err(dev, "failed to exit sleep mode: %d\n", ret);
			msleep(20);
		}
	} while (ret == -ETIMEDOUT);

	msleep(120);

	do {
		ret = mipi_dsi_generic_write(dsi, (u8[])
						{0xB3, 0x26, 0x08, 0x00, 0x20, 0x00}, 6);
		if (ret < 0) {
			dev_err(dev, "failed to set display interface setting: %d\n"
				, ret);
			msleep(20);
		}
	} while (ret == -ETIMEDOUT);
	mdelay(20);

	do {
		ret = mipi_dsi_dcs_set_display_on(dsi);
		if (ret < 0)
			dev_err(dev, "failed to set display on: %d\n", ret);

		msleep(20);
	} while (ret == -ETIMEDOUT);

	return ret;
}

static void jdi_panel_off(struct jdi_panel *jdi)
{
	struct mipi_dsi_device *dsi = jdi->dsi;
	struct device *dev = &jdi->dsi->dev;
	int ret;

	dsi->mode_flags |= MIPI_DSI_MODE_LPM;

	do {
		ret = mipi_dsi_dcs_set_display_off(dsi);
		if (ret < 0) {
			dev_err(dev, "failed to set display off: %d\n", ret);
			msleep(20);
		}
	} while (ret == -ETIMEDOUT);

	msleep(20);

	do {
		ret = mipi_dsi_dcs_enter_sleep_mode(dsi);
		if (ret < 0) {
			dev_err(dev, "failed to enter sleep mode: %d\n", ret);
			msleep(20);
		}
	} while (ret == -ETIMEDOUT);

	msleep(100);

	gpiod_set_value_cansleep(jdi->dcdc_en_gpio, 0);
	msleep(20);
}

static int jdi_panel_disable(struct drm_panel *panel)
{
	struct jdi_panel *jdi = to_jdi_panel(panel);

	if (!jdi->enabled)
		return 0;

	backlight_disable(jdi->backlight);

	jdi_panel_off(jdi);

	jdi->enabled = false;

	return 0;
}

static int jdi_panel_unprepare(struct drm_panel *panel)
{
	struct jdi_panel *jdi = to_jdi_panel(panel);
	struct device *dev = &jdi->dsi->dev;
	int ret;

	if (!jdi->prepared)
		return 0;

	jdi_panel_off(jdi);

	ret = regulator_bulk_disable(ARRAY_SIZE(jdi->supplies), jdi->supplies);
	if (ret < 0)
		dev_err(dev, "regulator disable failed, %d\n", ret);

	gpiod_set_value_cansleep(jdi->enable_gpio, 0);

	gpiod_set_value_cansleep(jdi->reset_gpio, 1);

	gpiod_set_value_cansleep(jdi->dcdc_en_gpio, 0);

	jdi->prepared = false;

	return 0;
}

static int jdi_panel_prepare(struct drm_panel *panel)
{
	struct jdi_panel *jdi = to_jdi_panel(panel);
	struct device *dev = &jdi->dsi->dev;
	int ret;

	if (jdi->prepared)
		return 0;

	ret = regulator_bulk_enable(ARRAY_SIZE(jdi->supplies), jdi->supplies);
	if (ret < 0) {
		dev_err(dev, "regulator enable failed, %d\n", ret);
		return ret;
	}

	msleep(20);

	gpiod_set_value_cansleep(jdi->dcdc_en_gpio, 1);
	usleep_range(10, 20);

	gpiod_set_value_cansleep(jdi->reset_gpio, 0);
	usleep_range(10, 20);

	gpiod_set_value_cansleep(jdi->enable_gpio, 1);
	usleep_range(10, 20);

	ret = jdi_panel_init(jdi);
	if (ret < 0) {
		dev_err(dev, "failed to init panel: %d\n", ret);
		goto poweroff;
	}

	ret = jdi_panel_on(jdi);
	if (ret < 0) {
		dev_err(dev, "failed to set panel on: %d\n", ret);
		goto poweroff;
	}

	jdi->prepared = true;

	return 0;

poweroff:
	ret = regulator_bulk_disable(ARRAY_SIZE(jdi->supplies), jdi->supplies);
	if (ret < 0)
		dev_err(dev, "regulator disable failed, %d\n", ret);

	gpiod_set_value_cansleep(jdi->enable_gpio, 0);

	gpiod_set_value_cansleep(jdi->reset_gpio, 1);

	gpiod_set_value_cansleep(jdi->dcdc_en_gpio, 0);

	return ret;
}

static int jdi_panel_enable(struct drm_panel *panel)
{
	struct jdi_panel *jdi = to_jdi_panel(panel);

	if (jdi->enabled)
		return 0;

	msleep(200);

	jdi_panel_on(jdi);

	backlight_enable(jdi->backlight);

	jdi->enabled = true;

	return 0;
}
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

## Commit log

2021-07-26 Initial commit of the JDI LT070ME05000 driver
2021-07-26 Add PCB design
    [Audio.sch, CM4_Connector.sch, Connectors.sch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]

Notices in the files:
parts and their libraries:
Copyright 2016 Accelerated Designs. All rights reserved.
